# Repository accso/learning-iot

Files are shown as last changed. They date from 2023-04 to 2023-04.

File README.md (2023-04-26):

# Learning IoT

Goody for Building IoT in Munich 25. - 27. April 2023.

## Images PCB

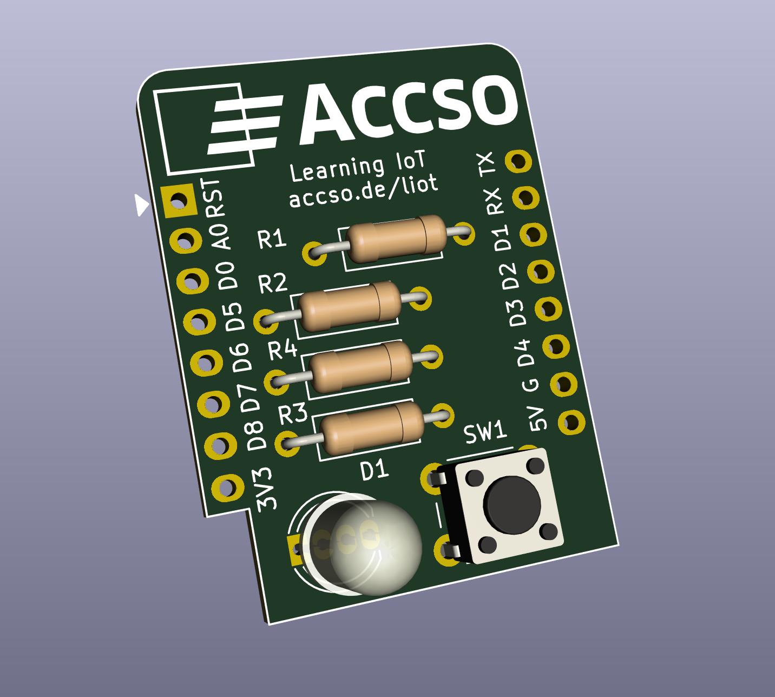
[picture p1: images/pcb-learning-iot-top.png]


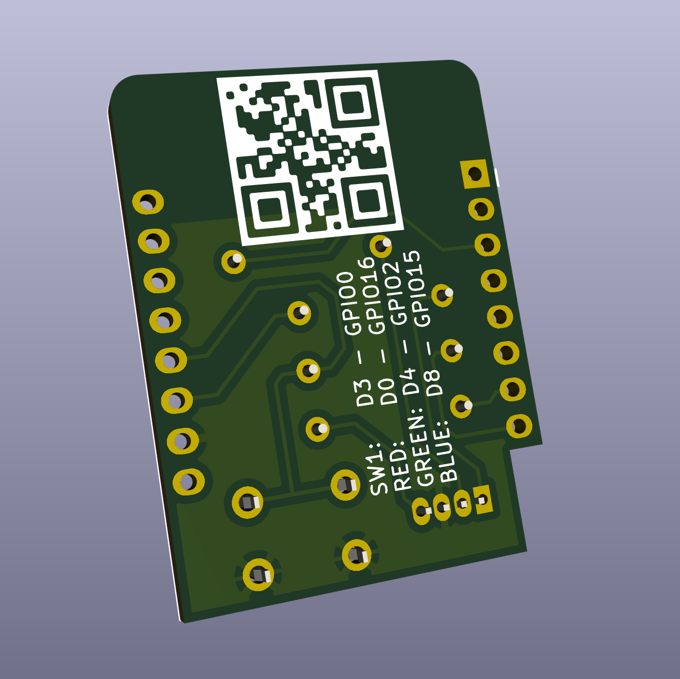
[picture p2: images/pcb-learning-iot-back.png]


## Pin List

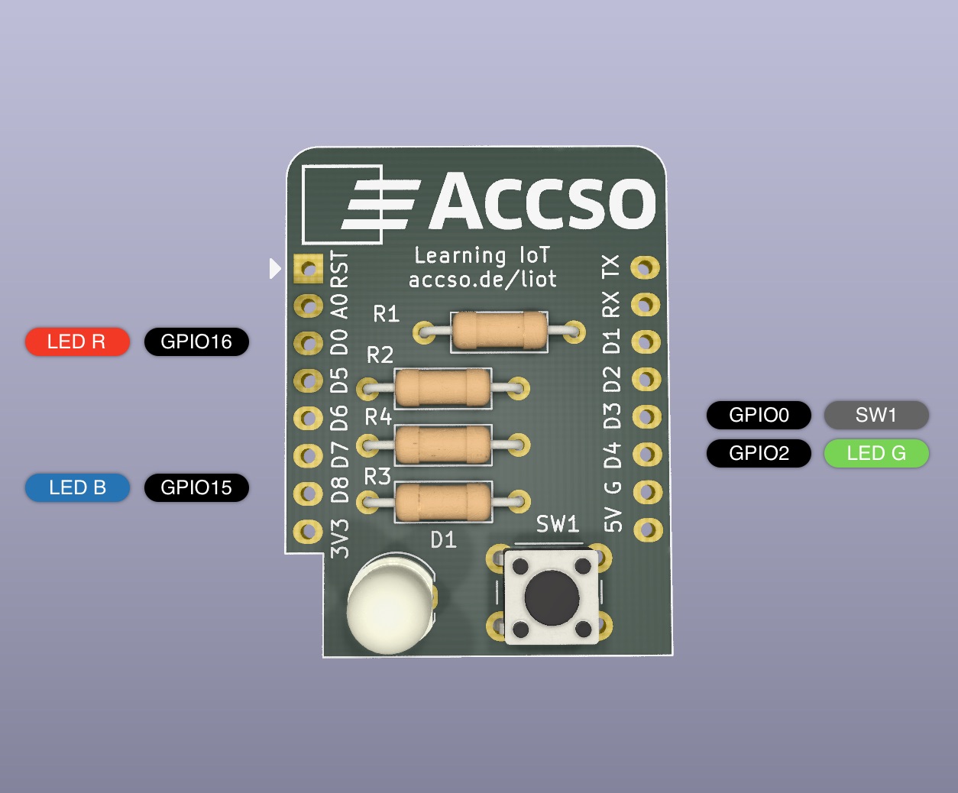
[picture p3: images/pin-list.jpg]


|  GPIO  |  Pin  |  Function |
|---|---|---|
| GPIO0  |  D3 | Button / SW1 |
| GPIO2  |  D4 | LED Green |
| GPIO15 |  D8 | LED Blue |
| GPIO16 |  D0 | LED Red |

## Bill of Materials (BOM)

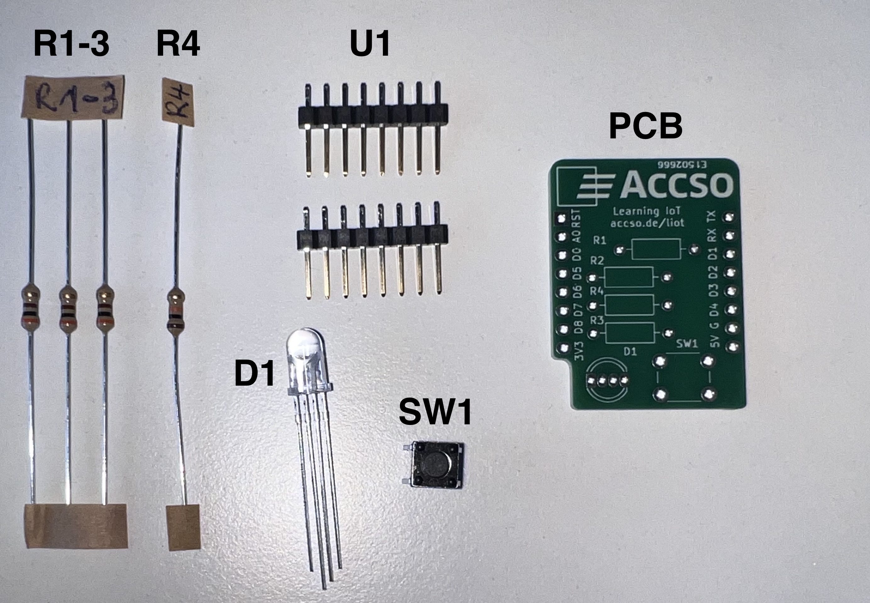
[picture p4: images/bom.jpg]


All components can be ordered at http://reichelt.de

| | | Order Number | Description |
|---|---|---|---|
| D1 | 1 | LED LL 5-8000RGBRGB-LED | 5 mm, bedrahtet, 4-Pin, rt/gn/bl, 8000 mcd, 25° |
| SW1  | 1 | TASTER 3301 | Kurzhubtaster 6x6mm, Höhe: 4,3mm, 12V, vertikal |
| U1 | 2 | MPE 087-1-008 | Stiftleisten 2,54 mm, 1X08, gerade |
| R4 | 1 | 1/4W 10K | Widerstand, Kohleschicht, 10 kOhm, 0207, 250 mW, 5 |
| R1-3 | 3 | 1/4W 300 | Widerstand, Kohleschicht, 300 Ohm, 0207, 250 mW, 5% |
| | 1 | ESD BEUTEL-S 127 | ESD PE-Abschirmbeutel, wiederverschließbar, 76 x 127 mm  |

## Schematic

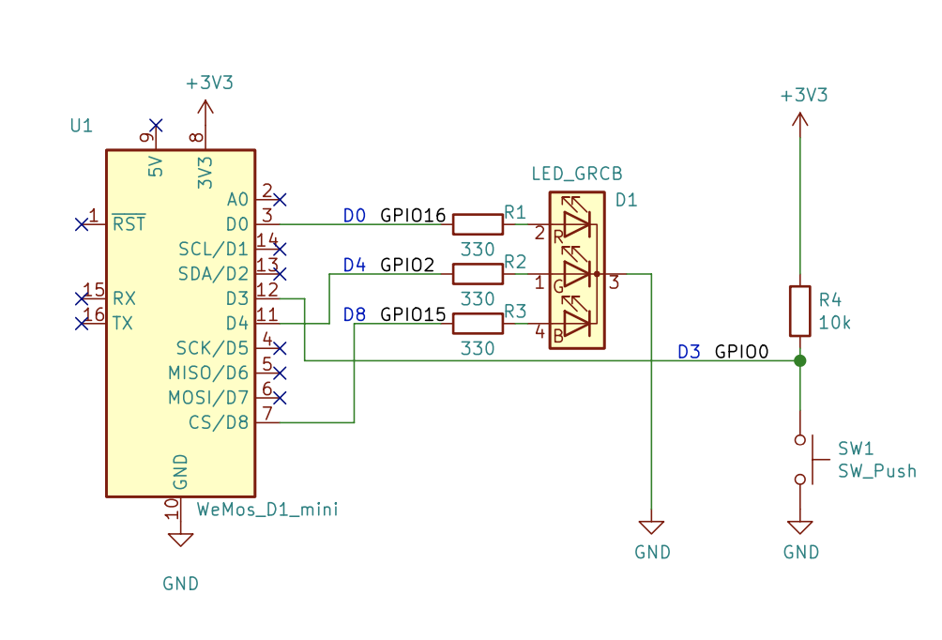
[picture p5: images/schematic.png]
[](schematic-accso-learning-iot-v1.0.pdf)

## Assembly

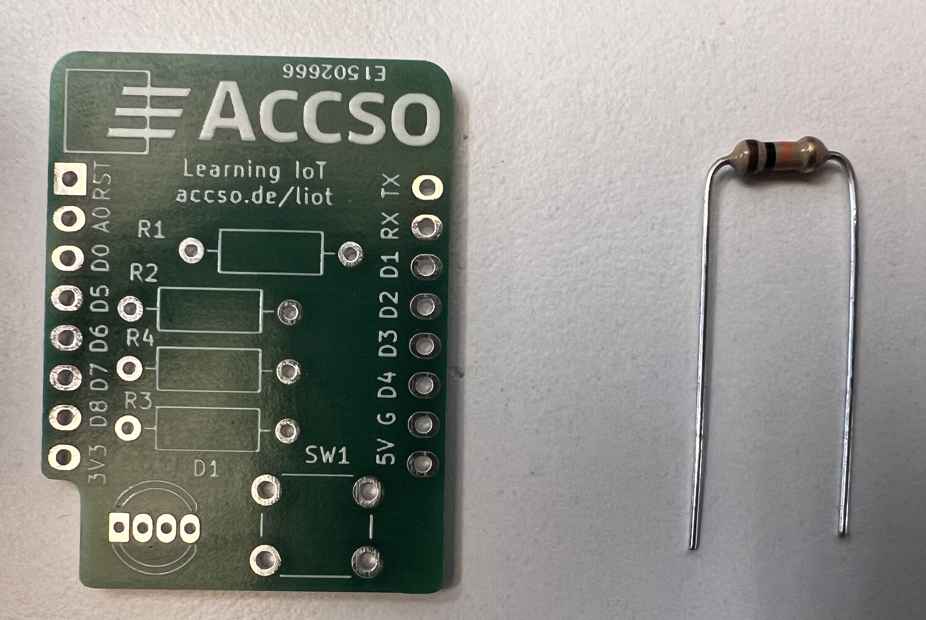
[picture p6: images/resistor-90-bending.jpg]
1) Bend the wires of the resistors by 90° <br>
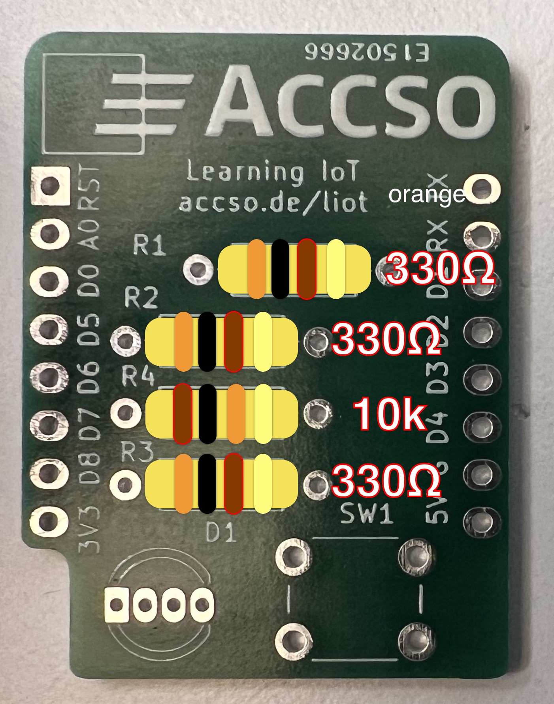
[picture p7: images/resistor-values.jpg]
2) Put the resistors through the holes (R4 is 10k while R1-3 is 330 Ohms)  <br>
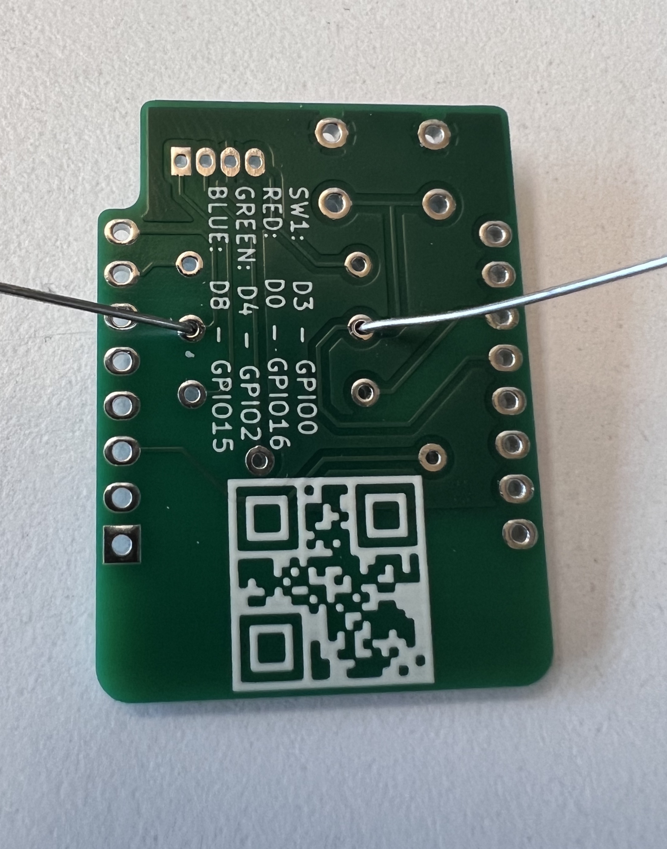
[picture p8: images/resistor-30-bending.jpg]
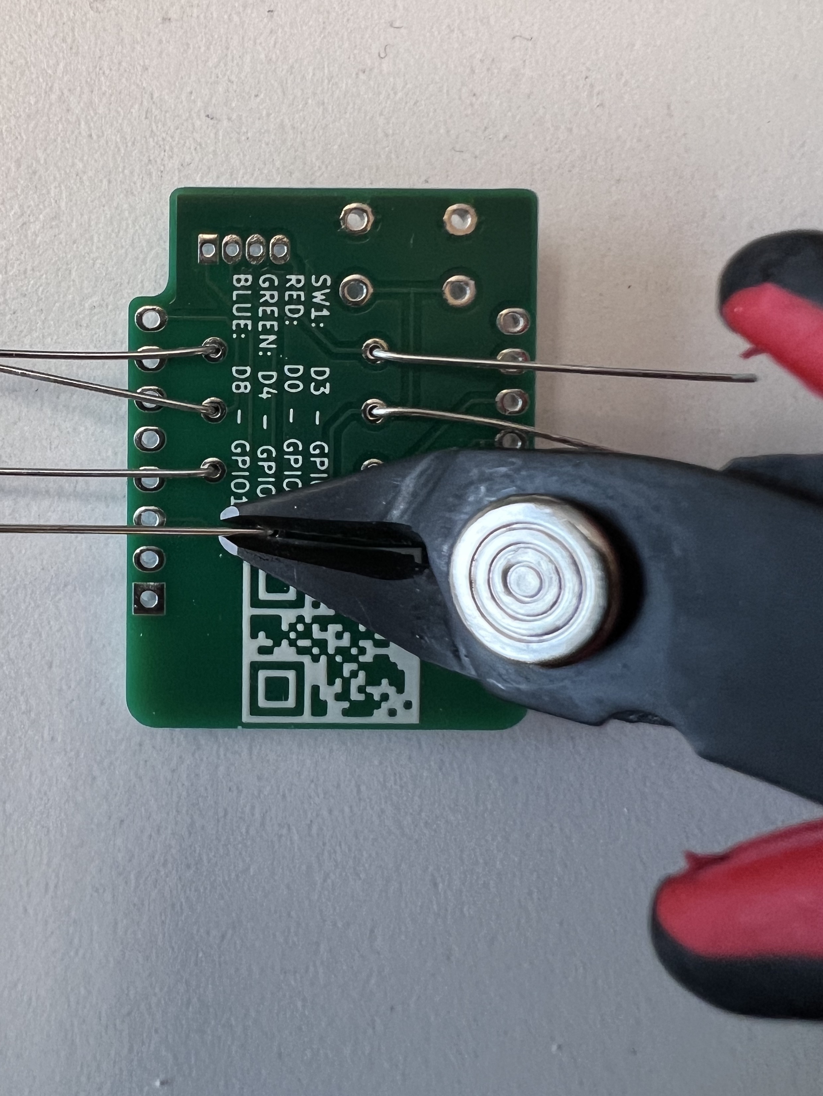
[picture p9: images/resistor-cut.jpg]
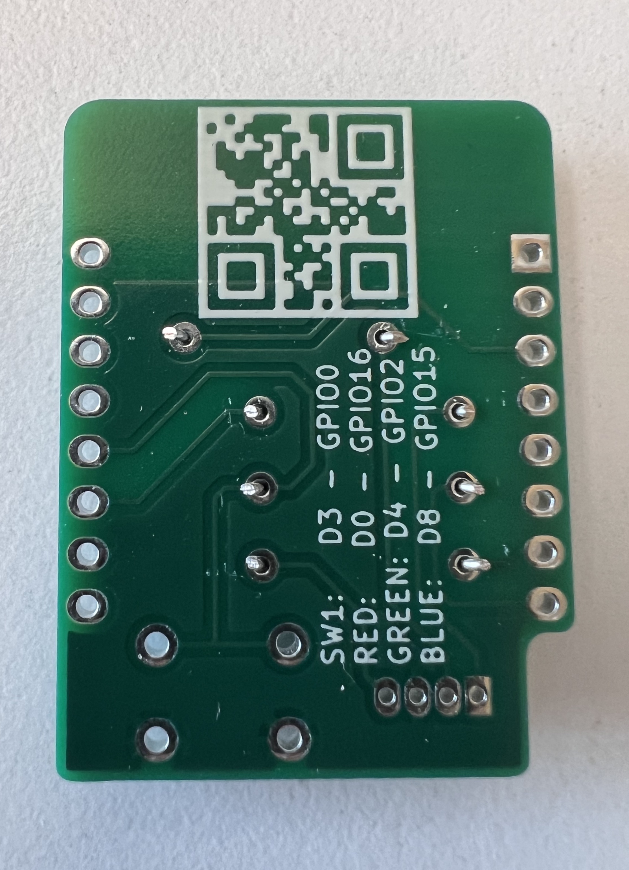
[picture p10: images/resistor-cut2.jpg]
3) Bend the wires by 30° and cut the pins, so 1mm wire is still visible from the bottom <br>  
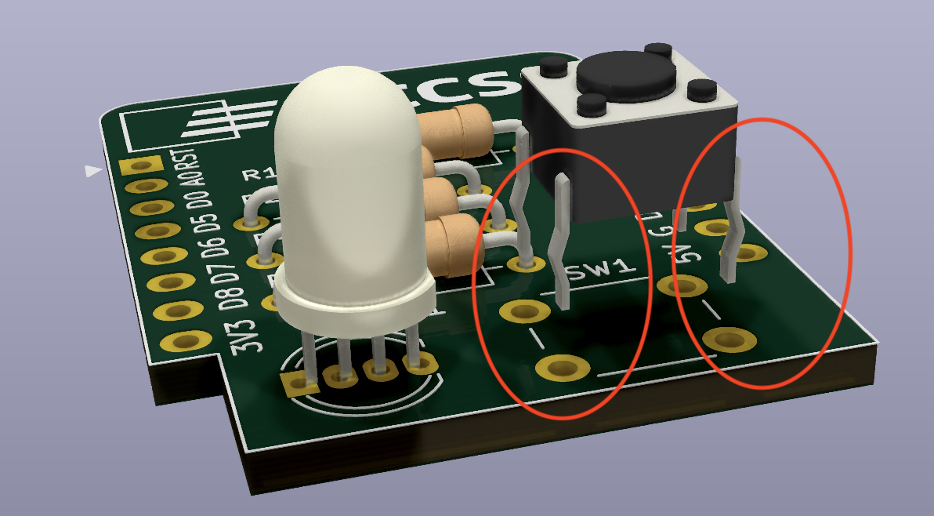
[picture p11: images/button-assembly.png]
4) Put the tactile button through the holes as described in following picture <br>
5) Put the LEDs through the holes with the flatted side pointed in direction of the push button
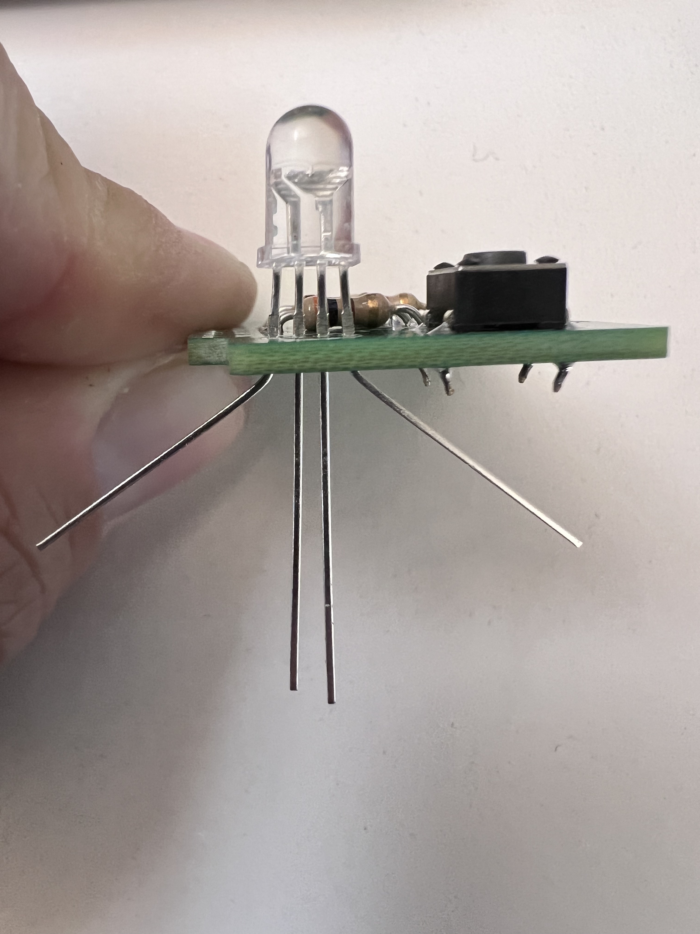
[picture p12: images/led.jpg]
6) Bend the outer wires by 30° and cut all wires, so 1mm wire is still visible from the bottom <br>
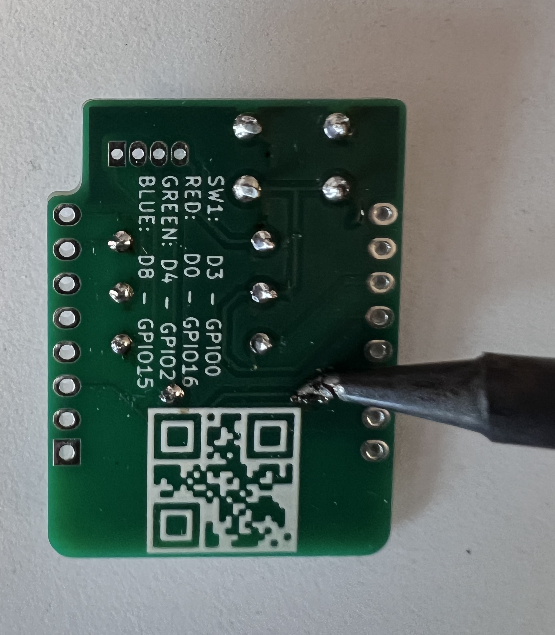
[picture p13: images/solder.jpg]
7) Solder all components <br>
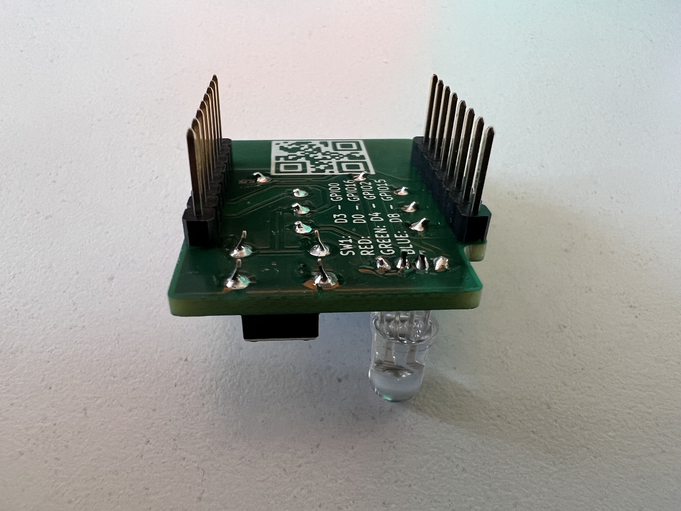
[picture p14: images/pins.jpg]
8) Solder the pin headers (male) downwards <br>
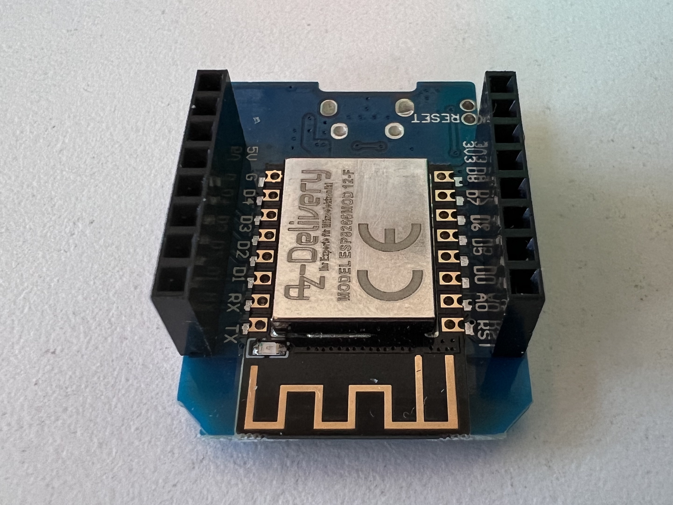
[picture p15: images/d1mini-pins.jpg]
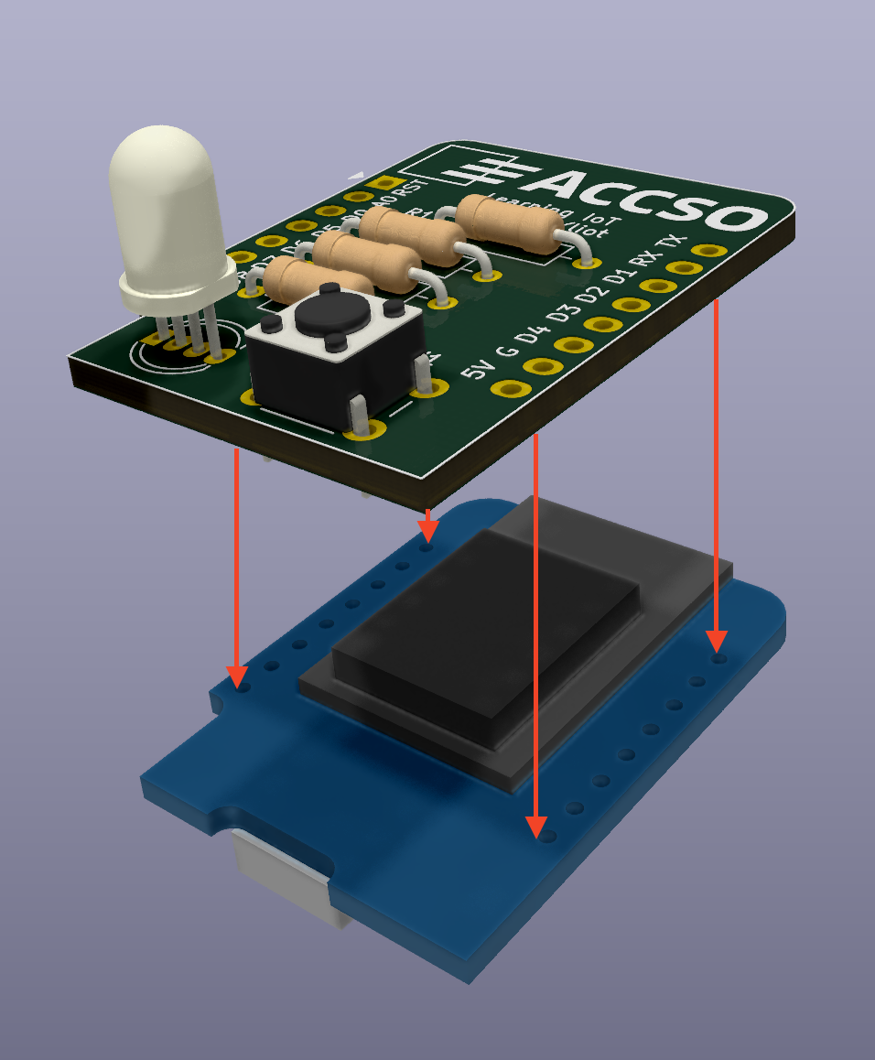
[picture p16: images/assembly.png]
9) Solder the pin headers (female) on top of D1 mini, so the shield can be put on top. <br><br>

## Flashing firmware

See the latest release at the release page of Github!

**Install Firmware:**
```
pip3 install esptool
python3 -m esptool --port /dev/tty.usbserial-1440 --baud 115200 erase_flash 
python3 -m esptool --port /dev/tty.SLAB_USBtoUART --baud 115200 write_flash 0x0 firmware-v1.0-esp8266_learning-iot.bin
```

**WiFi-AP:**
SSID: Accso Learning IoT
Key: Accso Learning IoT

**URL**
http://192.168.4.1
http://accso-learning-iot.local

**Config-Area:**
User: admin
Password: admin

## SW API

### Initialize Board

To initialize the Learning IoT Board requires as parameter the pointer to the web server handling REST-API calls.

```
LIoTBoard.begin(&webServer);
```

### Setting LEDs

```
void LIoTBoard.setLed(String color);

color: Color as string. Can be:
 - "black"
 - "red"
 - "green"
 - "yellow"
 - "blue"
 - "purple"
 - "cyan"
 - "white"
```

```
void LIoTBoard.setLed(bool bRed, bool bGreen, bool bBlue);

bRed: LED red true = on, false = off

bGreen: LED green true = on, false = off

bBlue: LED blue true = on, false = off
```

### Read button
```
bool LIoTBoard.getButtonPressed(void);

returns: true if button pressed and false if button is released
```

## Getting started

### Driving LED without board support

[basic.ino](firmware/examples/basic/basic.ino)
```
#define LED_RED    16 // D0
#define LED_GREEN   2 // D4
#define LED_BLUE   15 // D8
#define BUTTON      0 // D3

void setup(void)
{
    pinMode(LED_RED,OUTPUT);
    pinMode(LED_GREEN,OUTPUT);
    pinMode(LED_BLUE,OUTPUT);
    pinMode(BUTTON,INPUT);
}

void loop(void)
{
    // blink red LED
    digitalWrite(LED_RED,HIGH);
    delay(500);
    digitalWrite(LED_RED,LOW);
    delay(500);

    // blink green LED
    digitalWrite(LED_GREEN,HIGH);
    delay(500);
    digitalWrite(LED_GREEN,LOW);
    delay(500);

    // blink blue LED
    digitalWrite(LED_BLUE,HIGH);
    delay(500);
    digitalWrite(LED_BLUE,LOW);
    delay(500);

    // wait for button pressed (blocking)
    while(digitalRead(BUTTON))
    {
        delay(1);
    }
}
```

### Driving LED with board support

[board-support.ino](firmware/examples/board-support/board-support.ino)
```
# requires to add liotboard.h and liotboard.cpp to the project
#include "liotboard.h"

void setup(void)
{
    LIoTBoard.begin();

    LIoTBoard.setLed("red");
}

void loop(void)
{
    LIoTBoard.update();
    if (LIoTBoard.getButtonPressed())
    {
        LIoTBoard.setLed("green");
    } else
    {
        LIoTBoard.setLed("red");
    }
}
```

### REST API Example

POST data with JSON content /api/status:
- "red": LED Red, allowed values: "true" or "false"
- "green": LED Green, allowed values: "true" or "false"
- "blue": LED Blue, allowed values: "true" or "false"
- "button": Button change overwrite, allowed values: "true" or "false"

GET data as JSON format /api/status:
- "red": LED Red, allowed values: "true" or "false"
- "green": LED Green, allowed values: "true" or "false"
- "blue": LED Blue, allowed values: "true" or "false"
- "button": Button status, allowed values: "true" or "false"

[restapi.ino](firmware/examples/restapi/restapi.ino)
```
#include <ESP8266WiFi.h>
#include <WiFiClient.h>
#include <ESP8266WebServer.h>
#include <ESP8266mDNS.h>

# requires to add liotboard.h and liotboard.cpp to the project
#include "liotboard.h"

#ifndef STASSID
#define STASSID "your-ssid"
#define STAPSK "your-password"
#endif

const char* ssid = STASSID;
const char* password = STAPSK;

ESP8266WebServer server(80);

void handleRoot() {
  server.send(200, "text/plain", "hello from esp8266!\r\n");
}

void setup(void) {
  Serial.begin(115200);
  WiFi.mode(WIFI_STA);
  WiFi.begin(ssid, password);
  Serial.println("");

  // Wait for connection
  while (WiFi.status() != WL_CONNECTED) {
    delay(500);
    Serial.print(".");
  }
  Serial.println("");
  Serial.print("Connected to ");
  Serial.println(ssid);
  Serial.print("IP address: ");
  Serial.println(WiFi.localIP());

  if (MDNS.begin("esp8266")) { Serial.println("MDNS responder started"); }

  LIoTBoard.begin(&server);
  server.on("/", handleRoot);

  server.begin();
  Serial.println("HTTP server started");
}

void loop(void) {
  server.handleClient();
  MDNS.update();
}
```

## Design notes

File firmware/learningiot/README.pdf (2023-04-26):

README.md | 26.4.2023

# Learning IoT

Goody for Building IoT in Munich 25. - 27. April 2023.

## Images PCB

## Pin List

GPIO | Pin | Function
GPIO0 | D3 | Button / SW1
GPIO2 | D4 | LED Green
GPIO15 | D8 | LED Blue
GPIO16 | D0 | LED Red

## Bill of Materials (BOM)

All components can be ordered at http://reichelt.de

| | Order Number | Description
D1 | 1 | LED LL 5-8000RGBRGB-LED | 5 mm, bedrahtet, 4-Pin, rt/gn/bl, 8000 mcd, 25°
SW1 | 1 | TASTER 3301 | Kurzhubtaster 6x6mm, Höhe: 4,3mm, 12V, vertikal
U1 | 2 | MPE 087-1-008 | Stiftleisten 2,54 mm, 1X08, gerade
R4 | 1 | 1/4W 10K | Widerstand, Kohleschicht, 10 kOhm, 0207, 250 mW, 5
R1-3 3 | 1/4W 300 | Widerstand, Kohleschicht, 300 Ohm, 0207, 250 mW, 5%
| 1 | ESD BEUTEL-S 127 | ESD PE-Abschirmbeutel, wiederverschließbar, 76 x 127 mm

## Schematic

## Assembly

. Bend the wires of the resistors by 90°

. Put the resistors through the holes (R4 is 10k while R1-3 is 330 Ohms)

. Bend the wires by 30° and cut the pins, so 1mm wire is still visible from the bottom

. Put the tactile button through the holes as described in following picture

. Put the LEDs through the holes with the flatted side pointed in direction of the push button . Bend the outer wires by 30° and cut all wires, so 1mm wire is still visible from the bottom

. Solder all components

. Solder the pin headers (male) downwards

. Solder the pin headers (female) on top of D1 mini, so the shield can be put on top.

## Flashing firmware

See the latest release at the release page of Github!

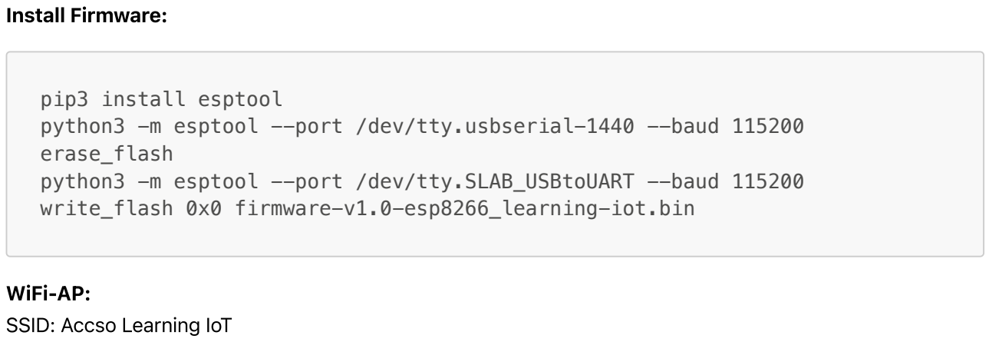
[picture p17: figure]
Install Firmware:; pip3 install esptool; erase_flash; write_flash 0x0 firmware-v1.0-esp8266_learning-iot.bin; WiFi-AP: SSID: Accso Learning IoT

python3 -m esptool --port /dev/tty.usbserial-1440 --baud 115200

python3 -m esptool --port /dev/tty.SLAB_USBtoUART --baud 115200

Key: Accso Learning IoT

URL
http://192.168.4.1
http://accso-learning-iot.local

Config-Area:
User: admin
Password: admin

## SW API

### Initialize Board

To initialize the Learning IoT Board requires as parameter the pointer to the web server handling REST-API

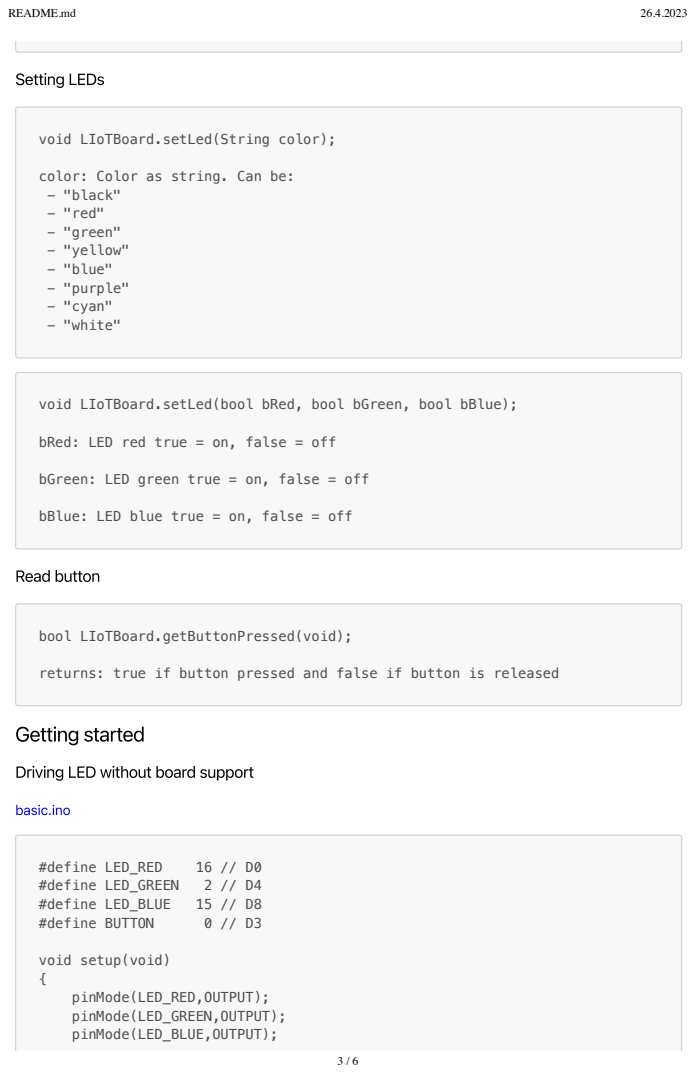
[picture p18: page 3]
Setting LEDs; Read button; Getting started; basic.ino; #define LED_RED; #define LED_GREEN; #define LED_BLUE; #define BUTTON

void LIoTBoard.setLed(String color);

color: Color as string. Can be:
- "black"
- "red"
- "green"
- "yellow"
- "blue"
- "purple"
- "cyan"
- "white"

void LIoTBoard.setLed(bool bRed, bool bGreen, bool bBlue);

bRed: LED red true = on, false = off

bGreen: LED green true = on, false = off

bBlue: LED blue true = on, false = off

bool LIoTBoard.getButtonPressed(void);

returns: true if button pressed and false if button is released

Driving LED without board support

void setup(void)
pinMode(LED_RED,OUTPUT);
pinMode(LED_GREEN,OUTPUT);
pinMode(LED_BLUE,OUTPUT);

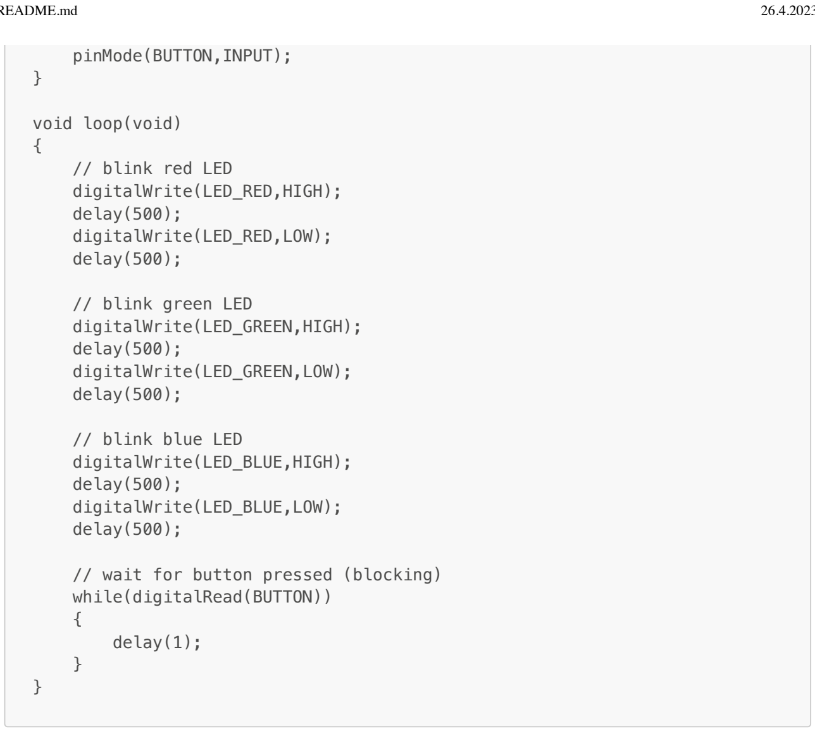
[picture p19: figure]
pinMode(BUTTON,INPUT);; void loop(void) {; // blink red LED digitalWrite(LED_RED,HIGH); delay(500); digitalWrite(LED_RED,LOW); delay(500);; // blink green LED digitalWrite(LED_GREEN,HIGH); delay(500); digitalWrite(LED_GREEN,LOW); delay(500);; // blink blue LED digitalWrite(LED_BLUE,HIGH); delay(500); digitalWrite(LED_BLUE,LOW); delay(500);; // wait for button pressed (blocking) while(digitalRead(BUTTON)) {; delay(1);

### Driving LED with board support

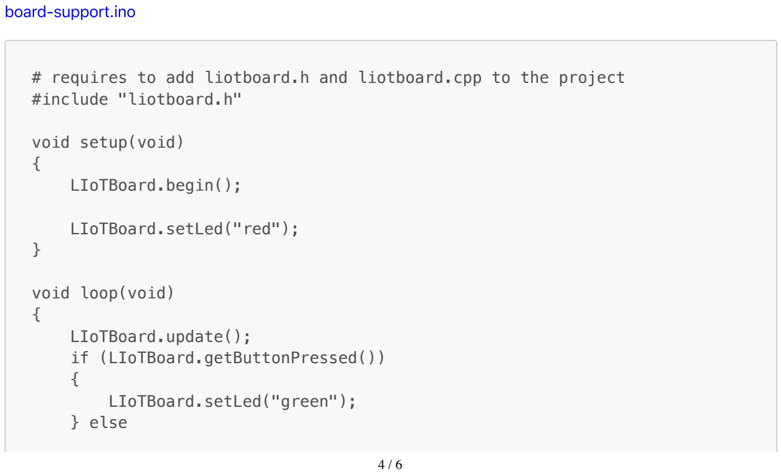
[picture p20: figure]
board-support.ino; #include "liotboard.h"; void setup(void) {; LIoTBoard.begin();; LIoTBoard.setLed("red");; void loop(void) {; LIoTBoard.update(); if (LIoTBoard.getButtonPressed()) {; LIoTBoard.setLed("green"); } else

# requires to add liotboard.h and liotboard.cpp to the project

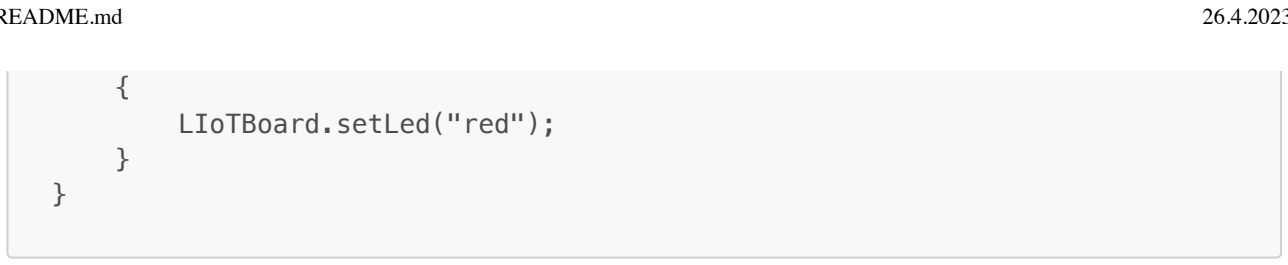
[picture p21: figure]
LIoTBoard.setLed("red");

### REST API Example

POST data with JSON content /api/status:

"red": LED Red, allowed values: "true" or "false"
"green": LED Green, allowed values: "true" or "false"
"blue": LED Blue, allowed values: "true" or "false"
"button": Button change overwrite, allowed values: "true" or "false"

GET data as JSON format /api/status:

"red": LED Red, allowed values: "true" or "false"
"green": LED Green, allowed values: "true" or "false" "blue": LED Blue, allowed values: "true" or "false" "button": Button status, allowed values: "true" or "false"

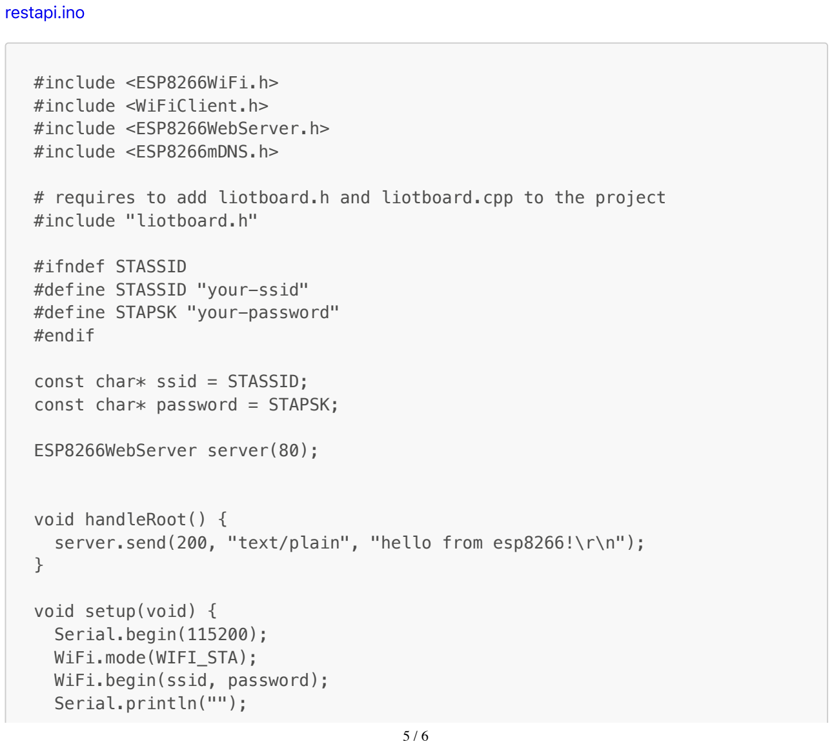
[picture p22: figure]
restapi.ino; #include <ESP8266WiFi.h> #include <WiFiClient.h> #include <ESP8266WebServer.h> #include <ESP8266mDNS.h>; #include "liotboard.h"; #ifndef STASSID #define STASSID "your-ssid" #define STAPSK "your-password" #endif; const char* ssid = STASSID; const char* password = STAPSK;; ESP8266WebServer server(80);; void handleRoot() { server.send(200, "text/plain", "hello from esp8266!\r\n");; void setup(void) { Serial.begin(115200); WiFi.mode(WIFI_STA); WiFi.begin(ssid, password); Serial.println("");

# requires to add liotboard.h and liotboard.cpp to the project

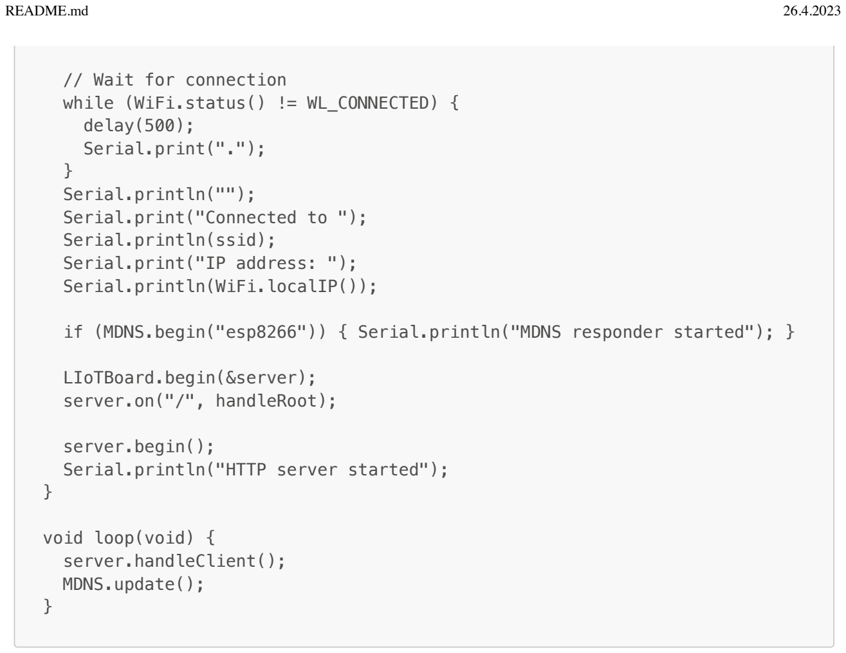
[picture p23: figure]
// Wait for connection while (WiFi.status() != WL_CONNECTED) { delay(500); Serial.print(".");; } Serial.println(""); Serial.print("Connected to "); Serial.println(ssid); Serial.print("IP address: "); Serial.println(WiFi.localIP());; LIoTBoard.begin(&server); server.on("/", handleRoot);; server.begin(); Serial.println("HTTP server started");; void loop(void) { server.handleClient(); MDNS.update();

if (MDNS.begin("esp8266")) { Serial.println("MDNS responder started"); }

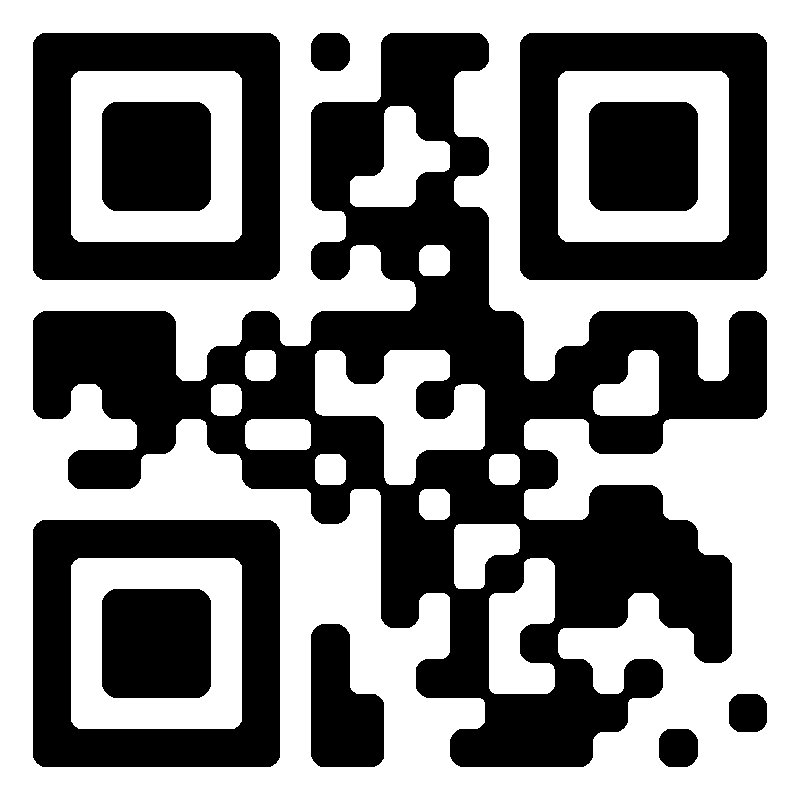
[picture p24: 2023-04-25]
images/qr-accso.de-liot.png

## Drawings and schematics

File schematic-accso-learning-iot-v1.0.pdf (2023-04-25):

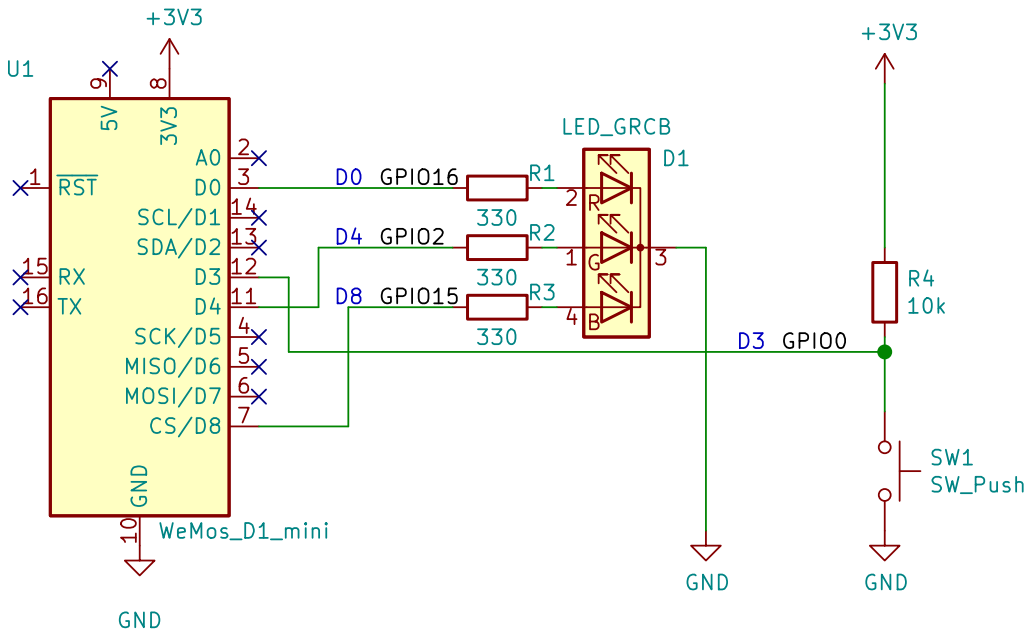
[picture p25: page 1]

File: learning-iot.sch Sheet: / Accso - Accelerated Solution GmbH

Id: 1/1 Title: Accso - Learning IoT

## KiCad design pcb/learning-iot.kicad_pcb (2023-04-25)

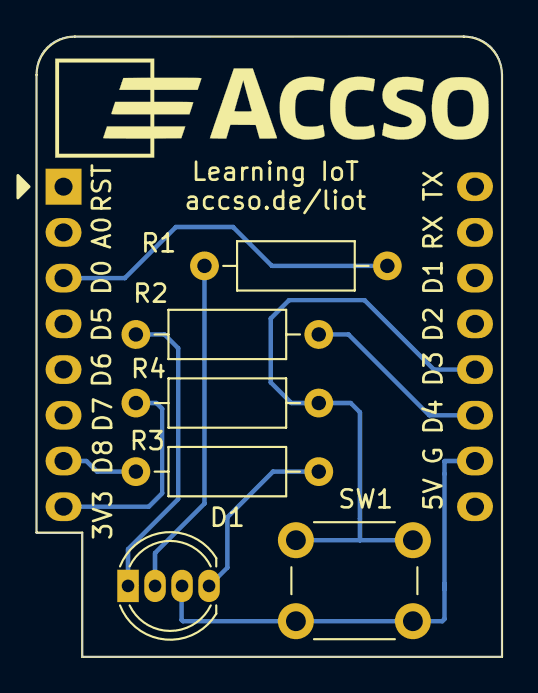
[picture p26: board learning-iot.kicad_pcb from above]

Board: 2 copper layers, 25.8 x 34.5 mm, 7 parts (0 on the bottom side), 9 nets.

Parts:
D1: LED_GRCB; LEDLL5-8000RGB
R1, R2, R3, R4: R; R_Axial_DIN0207_L6.3mm_D2.5mm_P10.16mm_Horizontal
SW1: SW_Push; SW_PUSH_6mm_H4.3mm
U1: WeMos_D1_mini; WEMOS_D1_mini_light

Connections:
+3V3: R4.1, U1.8
GND: D1.3, SW1.2, U1.10
unnamed: D1.1, R2.1
unnamed: D1.2, R1.1
unnamed: D1.4, R3.1
unnamed: R1.2, U1.3
unnamed: R2.2, U1.11
unnamed: R3.2, U1.7
unnamed: R4.2, SW1.1, U1.12

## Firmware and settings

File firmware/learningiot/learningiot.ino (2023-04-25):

/*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
 *******************************************************************************
 */

/**
 *******************************************************************************
 **\file learningiot.ino
 *******************************************************************************
 */

/**
 *******************************************************************************
 ** Include files
 *******************************************************************************
 */

//#define USE_TIME_FUNCTIONS

#if defined(USE_TIME_FUNCTIONS)
#include <ESPDateTime.h>
#include <DateTime.h>
#include <TimeElapsed.h>
#include <DateTimeTZ.h>
#endif

#include <Arduino.h>

#if defined(ARDUINO_ARCH_ESP8266)
#include <ESP8266WiFi.h>
#elif defined(ARDUINO_ARCH_ESP32)
#include <WiFi.h>
#else
#error Not supported architecture
#endif
#include <WiFiClient.h>

#if defined(ARDUINO_ARCH_ESP8266)
#include <ESP8266WebServer.h>
#include <ESP8266mDNS.h>
#elif defined(ARDUINO_ARCH_ESP32)
#include <WebServer.h>
#include <ESPmDNS.h>
#else
#error Not supported architecture
#endif


#include "esp32wifi.h"
#include "appwebserver.h"
#include "appconfig.h"
#include "espwebupdater.h"
#include "userledbutton.h"
#include "liotboard.h"

/**
 *******************************************************************************
 ** Local pre-processor symbols/macros ('#define') 
 *******************************************************************************
 */

/**
 *******************************************************************************
 ** Global variable definitions (declared in header file with 'extern') 
 *******************************************************************************
 */

/**
 *******************************************************************************
 ** Local type definitions ('typedef') 
 *******************************************************************************
 */


/**
 *******************************************************************************
 ** Local variable definitions ('static') 
 *******************************************************************************
 */

const char *ssidAp = "Accso Learning IoT";
const char *passwordAp = "Accso Learning IoT";
const char *hostName = "accso-learning-iot";

static int minsLast = 0;
static int hoursLast = 0;
static int daysLast = 0;
static uint32_t u32LastMillis = 0;
static uint8_t u8StateMachine = 0;
static uint32_t u32LightShowCounter = 0;
static uint32_t u32DemoCounter = 0;


#if defined(ARDUINO_ARCH_ESP8266)
static ESP8266WebServer webServer(80);
#elif defined(ARDUINO_ARCH_ESP32)
static WebServer webServer(80);
#endif

/**
 *******************************************************************************
 ** Local function prototypes ('static') 
 *******************************************************************************
 */

/**
 *******************************************************************************
 ** Function implementation - global ('extern') and local ('static') 
 *******************************************************************************
 */

void setup() {
  // put your setup code here, to run once:

  //intiate serial port
  Serial.begin(115200);
  Serial.println("");
  Serial.println("Welcome...");

  AppConfig_Init(&webServer);

  UserLedButton_Init();

  LIoTBoard.begin(&webServer);

  //initiate WIFI

#if defined(ARDUINO_ARCH_ESP8266)
  WiFi.hostname(hostName);
#elif defined(ARDUINO_ARCH_ESP32)
  WiFi.setHostname(hostName);
#endif

  Serial.println("Trying to connect with accesspoint (can take a while)...");
  Esp32Wifi_DualModeInit((char *)AppConfig_GetStaSsid(), (char *)AppConfig_GetStaPassword(), ssidAp, passwordAp);

  Serial.println("");
  Serial.print("IP address: ");
  Serial.println(WiFi.localIP());

  if (MDNS.begin(hostName)) {
    Serial.println("MDNS responder started");
  }

  EspWebUpdater_Init(&webServer);

  AppWebServer_Init(&webServer);

  webServer.begin();

#if defined(USE_TIME_FUNCTIONS)
  DateTime.setTimeZone("GMT-2");
  DateTime.begin();

  if (!DateTime.isTimeValid()) {
    Serial.println("Failed to get time from server.");
  } else {
    Serial.printf("Date Now is %s\n", DateTime.toISOString().c_str());
    Serial.printf("Timestamp is %ld\n", DateTime.now());
    DateTimeParts parts = DateTime.getParts();
    Serial.printf("H: %d M: %d\n", parts.getHours(), parts.getMinutes());
  }
#endif

  MDNS.addService("http", "tcp", 80);
  MDNS.addService("accso-learning-iot", "tcp", 80);

  //add your initial stuff here
}

void RunEveryMinute(uint8_t u8Hours, uint8_t u8Minutes) {
    
}

void RunEveryHour(uint8_t u8Hours, uint8_t u8Minutes) {
}

void RunEveryDay(uint8_t u8Hours, uint8_t u8Minutes) {
}

void LightShow()
{
    static bool bOldButton = false;
    if (LIoTBoard.getButtonPressed() != bOldButton)
    {
        bOldButton = LIoTBoard.getButtonPressed();
        delay(50);
        if (bOldButton)
        {
            u8StateMachine++;
        }
        u32DemoCounter = 30000;
    }

    if (u32LightShowCounter == 0)
    {
       if (u32DemoCounter == 0)
       {
           u8StateMachine++;
           u32LightShowCounter = 1000;
       }
    }

    switch(u8StateMachine)
    {
        case 1:
          LIoTBoard.setLed("red");
          break;
        case 2:
          LIoTBoard.setLed("yellow");
          break;
        case 3:
          LIoTBoard.setLed("green");
          break;
        case 4:
          LIoTBoard.setLed("cyan");
          break;
        case 5:
          LIoTBoard.setLed("blue");
          break;
        case 6:
          LIoTBoard.setLed("purple");
          break;
        default:
          u8StateMachine = 1;
          break;
    }
}

void diffUpdate(uint32_t* pu32Count, uint32_t u32Diff)
{
    if (*pu32Count > u32Diff)
    {
        *pu32Count -= u32Diff;
    } else
    {
        *pu32Count = 0;
    }
}

void loop() {
  bool bMinuteUpdated = false;
  bool bHourUpdated = false;
  bool bDayUpdated = false;
  uint32_t u32Diff;

#if defined(USE_TIME_FUNCTIONS)
  DateTimeParts parts = DateTime.getParts();
#endif

// put your main code here, to run repeatedly:
#if defined(ARDUINO_ARCH_ESP8266)
  MDNS.update();
#endif
  LightShow();
  AppWebServer_Update();
  Esp32Wifi_Update();
  AppWebServer_Update();
  LIoTBoard.update();

  u32Diff = millis() - u32LastMillis;
  if (u32Diff != 0) 
  {
      diffUpdate(&u32LightShowCounter, u32Diff);
      diffUpdate(&u32DemoCounter, u32Diff);
      u32LastMillis = millis();
  }

#if defined(USE_TIME_FUNCTIONS)
  if (minsLast != parts.getMinutes()) {
    RunEveryMinute(parts.getHours(), parts.getMinutes());
    minsLast = parts.getMinutes();
    bMinuteUpdated = true;
  }

  if (hoursLast != parts.getHours()) {
    if (hoursLast > parts.getHours()) {
      RunEveryDay(parts.getHours(), parts.getMinutes());
      bDayUpdated = true;
    }
    hoursLast = parts.getHours();
    RunEveryHour(parts.getHours(), parts.getMinutes());
    bHourUpdated = true;
    if (bMinuteUpdated == false) {
      RunEveryMinute(parts.getHours(), parts.getMinutes());
    }
  }
#endif

  //add your cyclic stuff here
}

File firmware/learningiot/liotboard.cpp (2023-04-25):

/*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
 *******************************************************************************
 */

/**
 *******************************************************************************
 **\file liotboard.cpp
 **
 ** Learning IoT Board Support
 ** A detailed description is available at
 ** @link LIoTBoardGroup file description @endlink
 **
 ** History:
 ** - 2023-4-20  1.00  Manuel Schreiner
 *******************************************************************************
 */

#define __LIOTBOARD_CPP__

/**
 *******************************************************************************
 ** Include files
 *******************************************************************************
 */


#include <string.h> //required also for memset, memcpy, etc.
#include <stdint.h>
#include <stdbool.h>
#include "liotboard.h"
#include <Arduino.h>
#include <ArduinoJson.h>

/**
 *******************************************************************************
 ** Local pre-processor symbols/macros ('#define') 
 *******************************************************************************
 */

#define LED_RED    16 // D0
#define LED_GREEN   2 // D4
#define LED_BLUE   15 // D8
#define BUTTON      0 // D3

const char* strColors[8] = {
  "black",   //0
  "red",     //1
  "green",   //2
  "yellow",  //3
  "blue",    //4
  "purple",  //5
  "cyan",    //6
  "white"    //7
};


/**
 *******************************************************************************
 ** Global variable definitions (declared in header file with 'extern') 
 *******************************************************************************
 */

bool bLedRed = true;
bool bLedGreen = false;
bool bLedBlue = false;

bool bButtonPressed = false;
bool bWebButtonPressed = false;
bool bHwButtonPressed = false;

#if defined(ARDUINO_ARCH_ESP8266)
ESP8266WebServer* pServer;
#else
WebServer* pServer;
#endif

char acTmp[256];
StaticJsonDocument<256> doc;

/**
 *******************************************************************************
 ** Local type definitions ('typedef') 
 *******************************************************************************
 */

/**
 *******************************************************************************
 ** Local variable definitions ('static') 
 *******************************************************************************
 */

/**
 *******************************************************************************
 ** Local function prototypes ('static') 
 *******************************************************************************
 */

static void handleAPI(void);
static void InitializeBoardHW(void);
#if defined(ARDUINO_ARCH_ESP8266)
  static void InitializeRestApi(ESP8266WebServer* pWebServer);
#else
  static void InitializeRestApi(WebServer* pWebServer);
#endif

/**
 *******************************************************************************
 ** Function implementation - global ('extern') and local ('static') 
 *******************************************************************************
 */



/**
 * \brief Handle requests at /api/status
 *
 */
static void handleAPI(void) {
    static bool bWebButtonPressedOld = false;
    if (pServer->method() == HTTP_GET) {
        LIoTBoard_GetJsonStatusString(acTmp,true);
        pServer->send(200, "text/plain", acTmp);
    } else if (pServer->method() == HTTP_POST)
    {
      Serial.printf("args: %d\r\n", pServer->args());
      if (pServer->args() == 1)
      {
          if (pServer->arg(0) != NULL)
          {
              Serial.printf("arg(0): %s\r\n", pServer->arg(0));
              deserializeJson(doc, pServer->arg(0));
              if (doc.containsKey("red"))
              {
                  bLedRed = doc["red"];
              }
              if (doc.containsKey("green"))
              {
                  bLedGreen = doc["green"];
              }
              if (doc.containsKey("blue"))
              {
                  bLedBlue = doc["blue"];
              }
              if (doc.containsKey("button"))
              {
                  bWebButtonPressed = doc["button"];
                  if (bWebButtonPressedOld != bWebButtonPressed)
                  {
                     bWebButtonPressedOld = bWebButtonPressed;
                     bButtonPressed = bWebButtonPressed;
                  }
              }
              pServer->send(200, "text/plain", "ok");
          } else
          {
              pServer->send(405, "text/plain", "error");
          }
      }
    }
    else
    {
        pServer->send(405, "text/plain", "error");
    }
}

static void InitializeBoardHW(void)
{
    pinMode(LED_RED,OUTPUT);
    pinMode(LED_GREEN,OUTPUT);
    pinMode(LED_BLUE,OUTPUT);
    pinMode(BUTTON,INPUT);
}

#if defined(ARDUINO_ARCH_ESP8266)
  static void InitializeRestApi(ESP8266WebServer* pWebServer)
#else
  static void InitializeRestApi(WebServer* pWebServer)
#endif
{
    pServer = pWebServer;
    if (pServer != NULL)
    {
        pServer->on("/api/status", handleAPI);
    }
}
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

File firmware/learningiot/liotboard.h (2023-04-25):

/*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
 *******************************************************************************
 */

/**
 *******************************************************************************
 **\file liotboard.cpp
 **
 ** Learning IoT Board Support
 ** A detailed description is available at
 ** @link LIoTBoardGroup file description @endlink
 **
 ** History:
 ** - 2023-4-20  1.00  Manuel Schreiner
 *******************************************************************************
 */

#if !defined(__LIOTBOARD_H__)
#define __LIOTBOARD_H__


/**
 *******************************************************************************
 ** \defgroup LIoTBoardGroup Learning IoT Board Support
 **
 ** Provided functions of LIoTBoard:
 **
 **
 *******************************************************************************
 */

//@{

/**
 *******************************************************************************
** \page liotboard_module_includes Required includes in main application
** \brief Following includes are required
** @code
** #include "liotboard.h"
** @endcode
**
 *******************************************************************************
 */

/**
 *******************************************************************************
 ** (Global) Include files
 *******************************************************************************
 */


#if defined(ARDUINO_ARCH_ESP8266)
  #include <ESP8266WebServer.h>
#elif defined(ARDUINO_ARCH_ESP32)
  #include <WebServer.h>
#endif

/**
 *******************************************************************************
 ** Global pre-processor symbols/macros ('#define') 
 *******************************************************************************
 */

/**
 *******************************************************************************
 ** Global type definitions ('typedef') 
 *******************************************************************************
 */

typedef enum en_liot_board_led_color
{
    LIoTBoardLedColorBlack = 0,
    LIoTBoardLedColorRed = 1,
    LIoTBoardLedColorGreen = 2,
    LIoTBoardLedColorBlue = 4,
    LIoTBoardLedColorYellow = 3,
    LIoTBoardLedColorCyan = 6,
    LIoTBoardLedColorPurple = 5,
    LIoTBoardLedColorWhite = 7 
} en_liot_board_led_color_t;

/**
 *******************************************************************************
 ** Global variable declarations ('extern', definition in C source)
 *******************************************************************************
 */

extern bool bLedRed;
extern bool bLedGreen;
extern bool bLedBlue;
extern bool bButtonPressed;

/**
 *******************************************************************************
 ** Global function prototypes ('extern', definition in C source) 
 *******************************************************************************
 */


#if defined(ARDUINO_ARCH_ESP8266)
  void LIoTBoard_Init(ESP8266WebServer* pWebServer);
#else
  void LIoTBoard_Init(WebServer* pWebServer);
#endif
void LIoTBoard_Deinit(void);
void LIoTBoard_Update(void);
void LIoTBoard_GetJsonStatusString(char* pstrOut,bool bUpdateAll);
bool LIoTBoard_GetButtonPressed(void);
en_liot_board_led_color_t LIoTBoard_ColorToEnum(const char* strColor);
const char* LIoTBoard_ColorEnumToString(en_liot_board_led_color_t enColor);
void LIoTBoard_SetLeds(bool bLedRedOnOff, bool bLedRedGreenOnOff, bool bLedBlueOnOff);
void LIoTBoard_GetLeds(bool* pbLedRedOnOff, bool* pbLedRedGreenOnOff, bool* pbLedBlueOnOff);
en_liot_board_led_color_t LIoTBoard_GetLedColor(void);
const char* LIoTBoard_GetLedColorString(void);
void LIoTBoard_SetLedColor(en_liot_board_led_color_t enColor);
void LIoTBoard_SetLedColorString(const char* strColor);

#ifdef __cplusplus
namespace liotboard {
  class LearningIotBoardClass
  {
  public:
    /**
    * @brief Enable board
    * @return whether success.
    */
    bool begin(void);
    
    /**
    * @brief Enable board
    * @return whether success.
    */
    #if defined(ARDUINO_ARCH_ESP8266)
      bool begin(ESP8266WebServer* pWebServer);
    #else
      bool begin(WebServer* pWebServer);
    #endif

    /**
    * @brief Disable board.
    * @return whether success.
    */
    bool end();

    void update();

    void setLed(en_liot_board_led_color_t enColor);

    void setLed(const char* strColor);

    void setLed(String strColor);

    void setLed(bool bRed, bool bGreen, bool bBlue);

    void setLed(bool bWhiteBlack);

    bool getButtonPressed(void);

    String getLedColorString(void);

    en_liot_board_led_color_t getLedColor(void);

  };
}

extern liotboard::LearningIotBoardClass LIoTBoard;



#endif

//@} // LIoTBoardGroup

#endif /* __LIOTBOARD_H__ */

/**
 *******************************************************************************
 ** EOF (not truncated)
 *******************************************************************************
 */

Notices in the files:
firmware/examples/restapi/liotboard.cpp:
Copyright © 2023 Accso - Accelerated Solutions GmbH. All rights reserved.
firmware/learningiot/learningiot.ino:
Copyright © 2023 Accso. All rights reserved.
